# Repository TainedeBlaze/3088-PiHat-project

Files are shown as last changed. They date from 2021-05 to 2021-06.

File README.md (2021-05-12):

# 3088-PiHat-project
# Taine de Buys
# 2021/05/12

brief description of what our PiHat does: 
We have designed a temperature sensor piHat, that will be able to measure the temperature of anything from a liquid to the ambient room temperature, and convey this temperature through a set out LED outputs. Each LED can be configured to turn on for when the temperature surpasses a designated threshold. This is done through a comparator op amp configuration and potentiometers for each LED. The circuit has 3 subsysetms, a voltage regulator that sets the voltage going into the LEDs, the temperature sensor itself, and the output LEDs which also have a status LED that shows whether the piHat is recieving power. 

Edits have now been made in a seperate branch to prove i know whats cracking

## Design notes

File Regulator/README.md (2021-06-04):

Brief description of buck-boost regulator subsystem: This subsystem at it's input takes in 3.3V from the RaspberryPi and ouputs a stable 4.3V line to power the 
comparator-LED configurations and the TMP135 temperature sensor.

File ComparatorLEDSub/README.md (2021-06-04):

Brief description of Comparator-LED subsystem: This subsystem comprises of three comparator-LED configurations that are designed in such a way to ouput a voltage of
over 0.7 Volts to each LED based on the output data of the TMP135 temperature sesnor. The first comparator configuration outputs a high voltage resulting in the LED
displaying when Vdata (Voltage output of TMP135) is in the range of 0 - 20 degrees celcius respectively. The second configuration outputs a high to the second LED 
when the temperature is in the range 20 - 40 degrees clecius, and the third when the temperature is in the range 40 degrees celcius and above. In the case of 40 
degrees clecius and above, all three LED's are displaying.

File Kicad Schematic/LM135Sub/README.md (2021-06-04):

Brief description of LM135 temperature sensor subsystem: This subsystem is comprised of the TMP135 temperature sensor which has its input (powering terminal) 
connected to the output of of the buck boost regulator subsystem, and its output (Vdata) connected to the comparator-LED subsystem. The TMP335 temperature sensor at
0℃ outputs 2.73V, increasing by 10mV/℃.

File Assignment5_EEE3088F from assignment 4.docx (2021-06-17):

EEE088F 2021 Assignment 5

Temperature Sensor PiHat

ALTMIC003, DGDC001, DBYTAI001

10/06/2021

# Executive Summary [5]

The following report describes the design process, each submodule of the PiHat in detail, as well as the PCB design/development, and finally includes a reflection on the full design process. Various conclusions were drawn over the design process and are discussed in this report.

Each submodule - namely the power supply, the Comparator-LED’s and the LM135 temperature sensor submodules respectively - is discussed in depth. Lastly, the PCB design is discussed, and attached are screenshots of both the 3D and 2D models of the PCB design. Furthermore, hyperlinks to the git repository containing all relevant data and information for this PiHat design are listed in this report.

# Introduction [5]

Our PiHat is an analogue temperature sensor. The purpose of the Hat is to allow the user to get a visual indication as to the surrounding temperature. Temperature sensors can be used to measure ambient room temperature, or as a probe to measure the temperature of liquids or the inside temperature regulated appliances like freezers and fridges.

The circuit is powered from the 3.3V output pin from the Raspberry pi and is grounded into pin 6. The daughter board takes the 3.3V input and passes it through a buck-boost regulator IC, boosting the voltage to a steady 4.3V output to the rest of the subsystems. A physical switch is incorporated and allowing for the user to turn the Hat on and off while still being plugged in. If the circuit is closed, an LED will turn on to show that there is a voltage being outputted from the switch. This output will then run into an analogue temperature sensor that will be covered in a waterproof casing, so that it may be used as a probe. 3 LEDs display the output. 1 LED will turn on if the temperature is above 0 degrees Celsius. 2 lights will come on for a temperature of above 25 degrees Celsius, and all 3 lights will turn on for if the temperature is above 50 degrees Celsius. This was done using voltage dividers and op -amps in comparator circuit configurations. However, the voltage dividers could be exchanged for potentiometers, as this would allow for the threshold temperature of each LED to be set by the user.

## Project Subsystems Block Diagram [5]

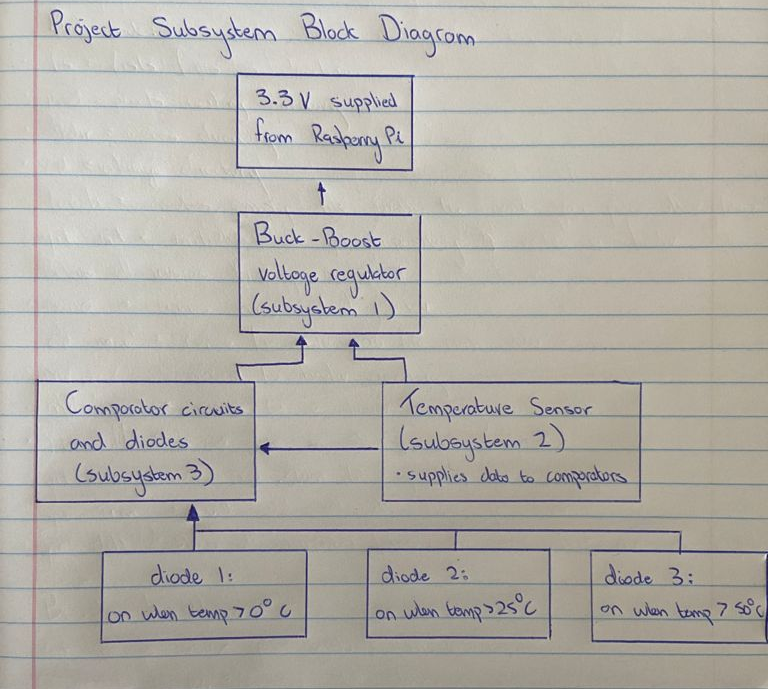
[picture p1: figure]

Figure 1: Subsystems Block Diagram.

# Design process [10]

The design process began by first specifying fixed meeting to delegate work and set sprint goals for each fortnite, with a design review happening with a tutor taking place in the weeks in between where we could discuss and reflect on progress. An initial idea was developed and use cases were specified. A circuit was developed comprising of 4 separate subsystems that met each of the requirements of our use cases

(available here: https://github.com/TainedeBlaze/3088-PiHat-project/blob/main/Project%20Submissions/EEE088F%202021%20Assignment%201%20.pdf (https://github.com/TainedeBlaze/3088-PiHat-project/blob/main/Project%20Submissions/EEE088F%202021%20Assignment%201%20.pdf))

After this submission, the team began to simulate each subsystem on LT Spice to see if the desired output would be achieved. Our first subsystem, the voltage regulator, became a source of concern as the initial design did not lie within the scope of the project design requirements. As such, this design evolved into a buck switching regulator, before finally a buck-boost voltage regulator IC component was chosen. Another point of inflection for the design came in our temperature sensor subsystem, as the LM355 sensors simulation had a different temperature to voltage relationship than the data sheets. This led to changing resistor values in order to hit the desired output.

(calculated and explained in depth here: https://github.com/TainedeBlaze/3088-PiHat-project/blob/main/Project%20Submissions/Assignment%202%20submission.pdf )

## Power Supply submodule [10]

This power supply submodule is solely made up of an LTC3442 integrated circuit which acts as a buck-boost regulator, providing a stable 4.4V output from the 3.3V input supplied by the RaspberryPi. In order for this submodule to work congruently with the rest of the circuit, it has to have various specifications that fit the criteria of the following two submodules (i.e the TMP135 temperature sensor submodule and the Comparator-LED submodule). These specifications include:

- Vin (pin 1) = 3.3V (DC supply from the RaspberryPi).
- Vout = 4.4V (This value is reached as a result of the external configuration of the LTC3442 integrated circuit).

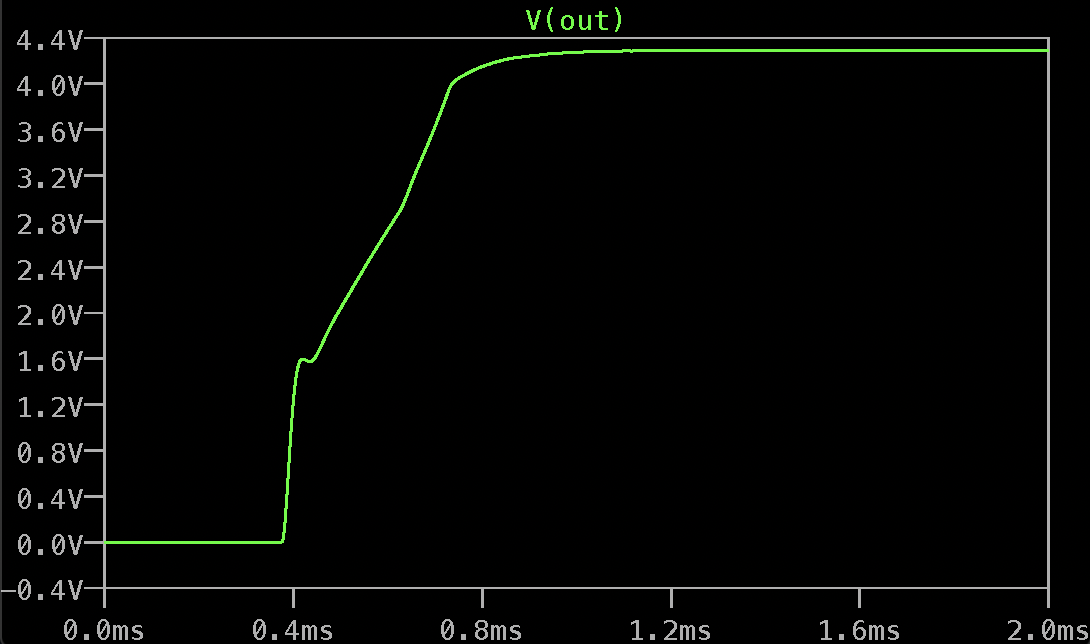
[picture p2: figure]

Figure 2: LT Spice simulation of Vout of the LTC3442 IC.

https://github.com/TainedeBlaze/3088-PiHat-project/blob/main/Regulator/BuckBoost.png

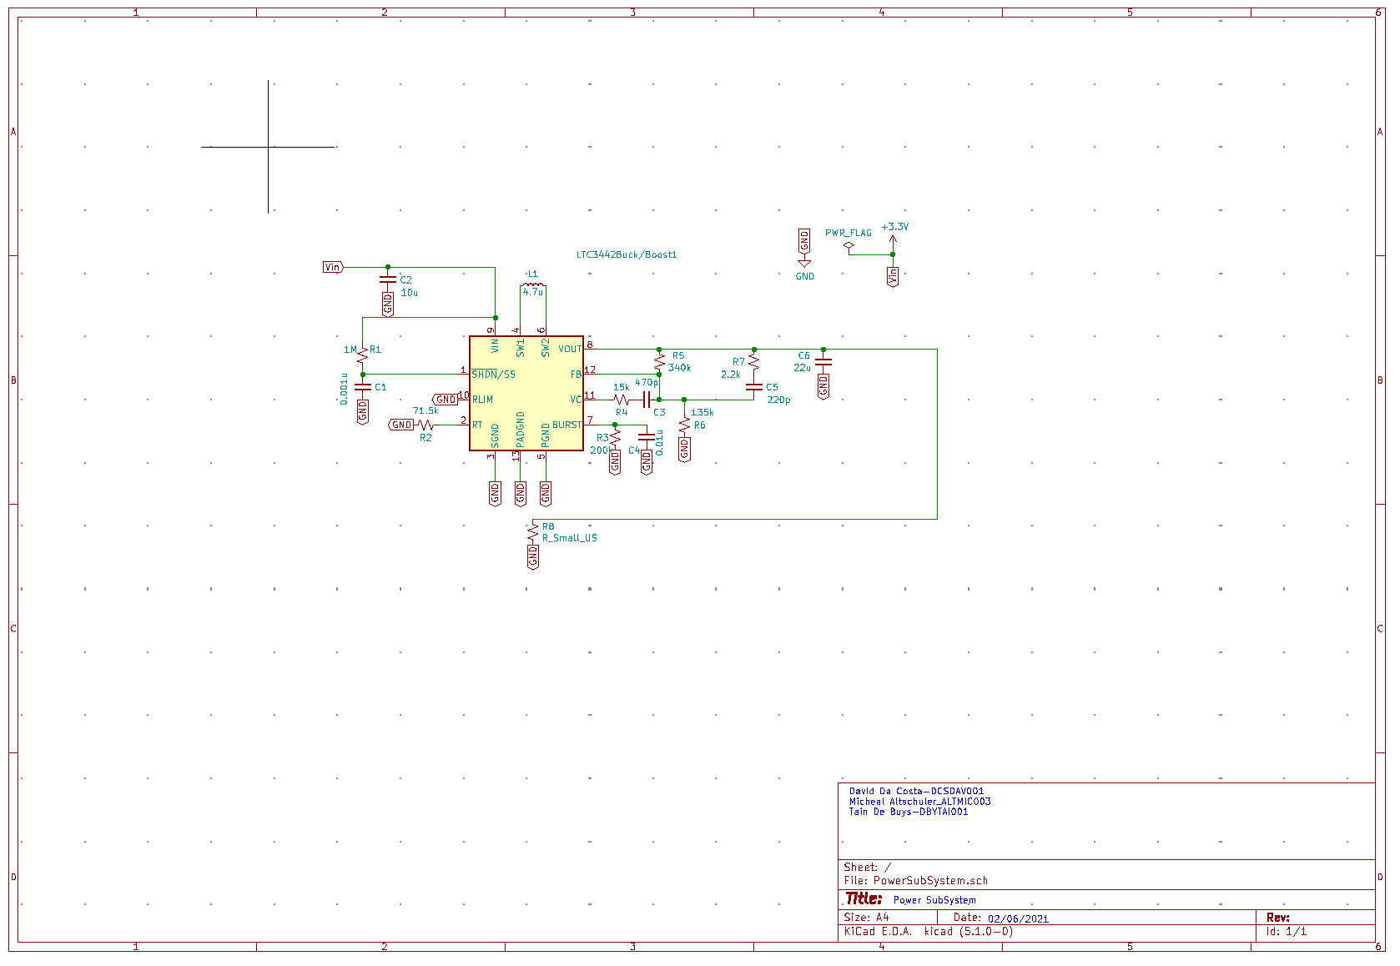
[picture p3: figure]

Figure 3: Screenshot of LTC3442 KiCad schematic

https://github.com/TainedeBlaze/3088-PiHat-project/blob/main/Regulator/BuckBoostKiCad.png

This submodule fits seamlessly into the design of the full circuit. It reliably outputs the desired 4.4V needed by the TMP135 and the comparator-LED configurations.

## Status Comparator-LEDs submodule [10]

This subsystem is made up of a series of comparator-LED configurations used to display the current temperature threshold met and to further display whether the circuit/PiHat is on (receiving power from the Buck Switch Regulator) or not. Three of the configurations have their non-inverting input connected to the TMP335 data line, and their inverting input connected to the 4.4V line supplied by the Buck Switch Regulator. Each of the three inverting inputs implement a voltage divider which determines when the comparator will output high based on the voltage supplied by the TMP335.

For the status LEDs, 3 simulations are run showing the 3 states that our output diodes are in. The thresholds were predefined as 0 ℃, 25 ℃ and 50 ℃ .

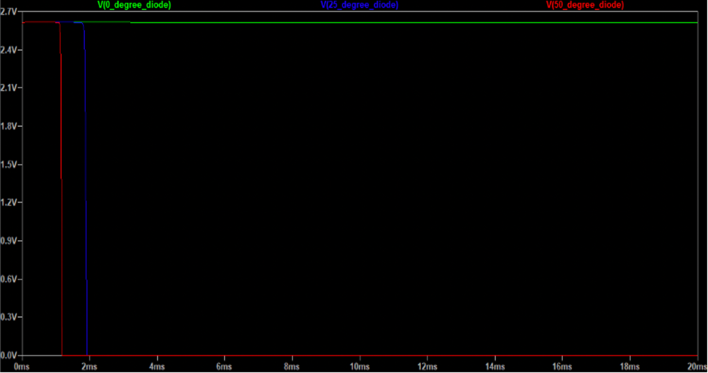
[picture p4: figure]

Figure 4: Simulation when temperature is 2°C .

https://github.com/TainedeBlaze/3088-PiHat-project/blob/main/ComparatorLEDSub/2degrees.png

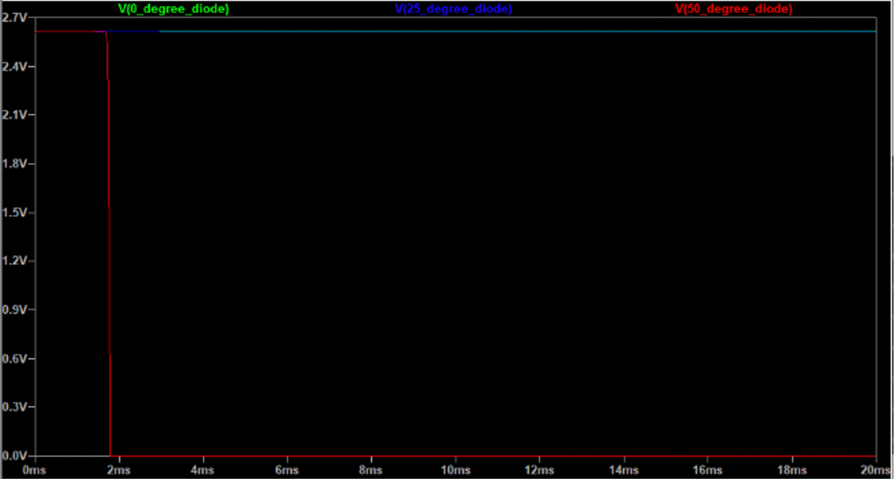
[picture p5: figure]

Figure 5: Simulation when temperature is 26°C .

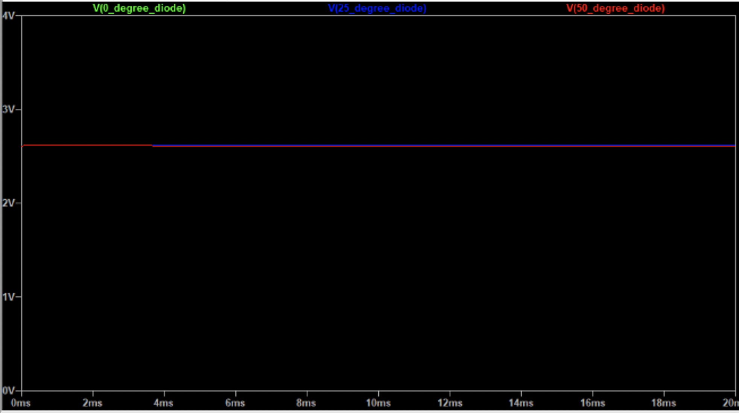
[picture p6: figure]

https://github.com/TainedeBlaze/3088-PiHat-project/blob/main/ComparatorLEDSub/26degrees.png

Figure 6: Simulation when temperature is 52°C .

https://github.com/TainedeBlaze/3088-PiHat-project/blob/main/ComparatorLEDSub/52degrees.png

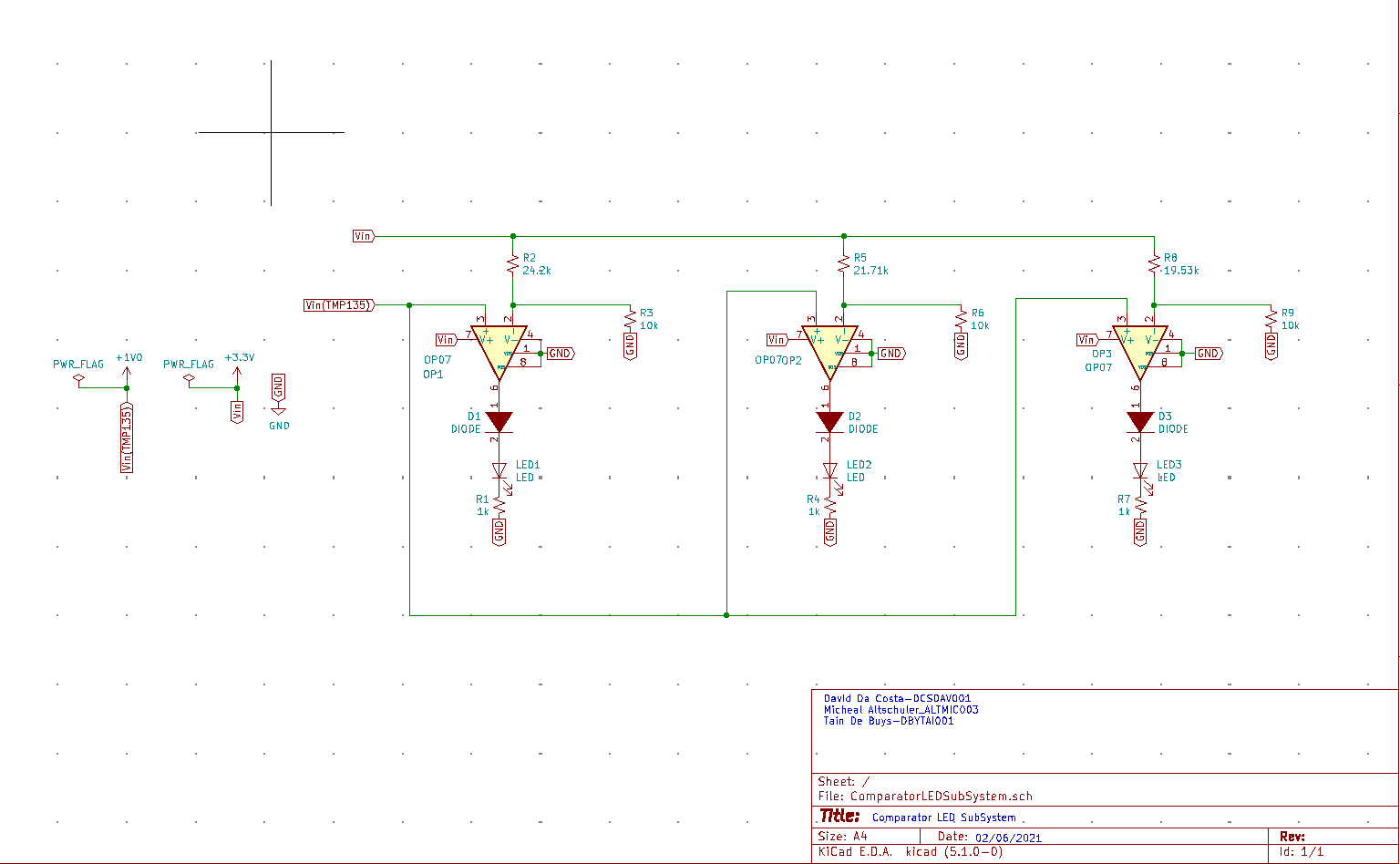
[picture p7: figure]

Figure 7: Screenshot of the Comparator-LED subsystem KiCad schematic.

https://github.com/TainedeBlaze/3088-PiHat-project/blob/main/ComparatorLEDSub/ComparatorLEDKiCad.png

According to all the theoretical conclusions drawn when designing this submodule, and from further subsequent LT Spice simulation, the status LED’s operate as they are supposed to. One LED will turn on within the first temperature range, two will turn on in the second, and finally all three will turn on in the third. It’s tough to draw a conclusion on the overall operation of this subsystem in a real-life situation as this circuit was only theoretically designed. However, if one did have to supply this subsystem with 4.4V (supplied by the LTC3442), it theoretically should work perfectly with no safety issues.

## LM135 Temperature Sensor submodule [10]

This subsystem is made up of the LM135 temperature sensor - the component being powered by the 4.4V line outputted by the Buck Switch Regulator, and further supplies the data needed by the comparator-LED configurations to output/display their temperature thresholds based on the voltage supplied by the LM335.

The LM355 temperature sensor was imported as an external library into LT Spice for the simulations. The data sheet supplied with the LM335 stated that the correlation between output voltage from the sensor and ambient temperature is given as: ∴V=5 ×10^(-3) T+1.2569 (eqn.1). Where T is measured in degrees Celsius.

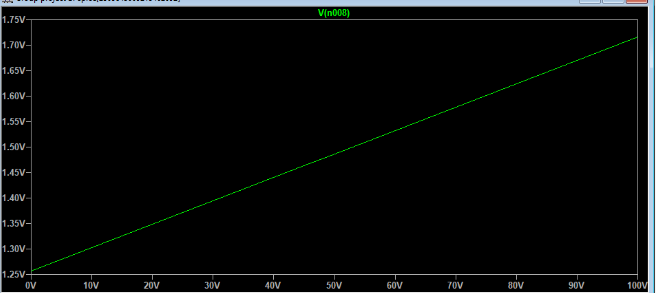
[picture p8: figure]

Figure 8: Output voltage of LM135 for different temperatures (specified on the x-axis).

https://github.com/TainedeBlaze/3088-PiHat-project/blob/main/LM135Sub/tmp135Simulation.png

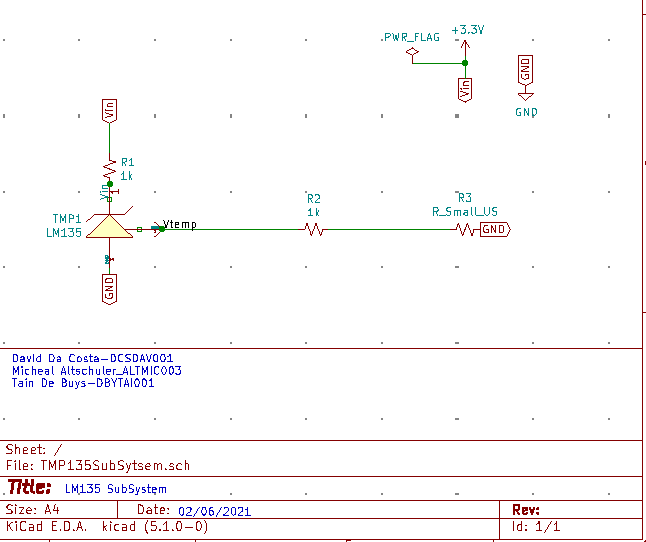
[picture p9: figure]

Figure: KiCad schematic for the LM135 submodule.

https://github.com/TainedeBlaze/3088-PiHat-project/blob/main/LM135Sub/LM135KiCad_Schematic%20.png

In conclusion to this subsystem, it can be said with certainty that it will operate in a real-life situation safely. However, after running a sweep across the temperature from 0 to 100 (depicted below where the x axis represents temperature), it was evident that the LT spice component had a slightly different relationship to the theoretical relationship specified. Thus, a new equation was calculated for the relationship between the output voltage of the sensor and the temperature discussed above (eqn.1). For the status LED’s to accurately display which temperature threshold is met, the LM335 needs to output the correct voltage to the comparators based on their respective temperature thresholds. From the LM335 data sheet, it was seen that at 0℃, the sensor would output 2.73V, increasing by 10mV/℃. However, after testing on LT Spice, a different outcome was observed. For experimental and circuit accuracy, the simulated results for Vdata were used in place of the theoretical values. This ensured that the status LEDs turned on at the correct temperatures. Thus, the specifications for this subsystem were accurately met through empirical evidence from the simulation rather than theory.

# Complete Schematic

The following image shows the final Pihat schematic containing all subsystems:

Figure Screenshot of complete Schematic

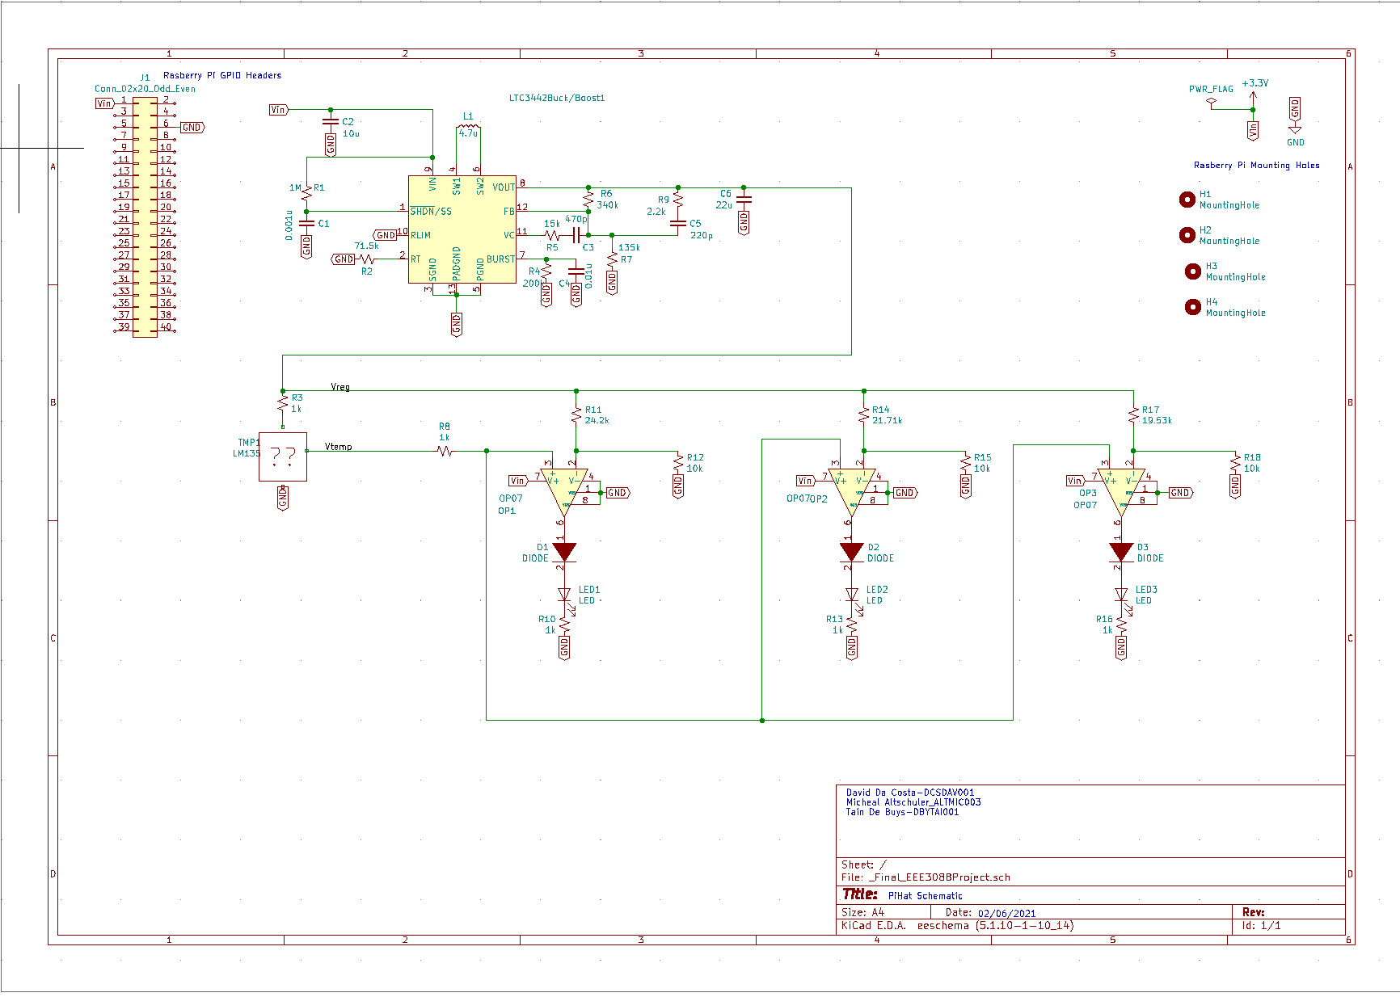
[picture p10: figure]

The schematic can be found using the following link:
https://github.com/TainedeBlaze/3088-PiHat-project/tree/main/Kicad%20Schematic

# PCB [10]

The dimensions of the PCB are: 65X30mm
The mounting hole’s diameters are 3.5mm
There are two connection points needed to be made to the Raspberry Pi Vin and GND these The Vin supplied should be connected to the 3.3V supply from the Raspberry Pi (pin 1) and the Ground (pin 6) Please note we have found an issue with our PCB as we have not properly formatted the size, input and ground pins. This will be adjusted before next submission.

The bill of materials can be found here :

https://github.com/TainedeBlaze/3088-PiHat-project/tree/main/PCB's%20Bill%20Of%20Materials

A how to guide on manufacturing one’s own temperature sensor PCB can be found using the following link:

https://github.com/TainedeBlaze/3088-PiHat-project/tree/main/Howto

How to use your PiHat link can be found below (same link as above):

https://github.com/TainedeBlaze/3088-PiHat-project/tree/main/Howto

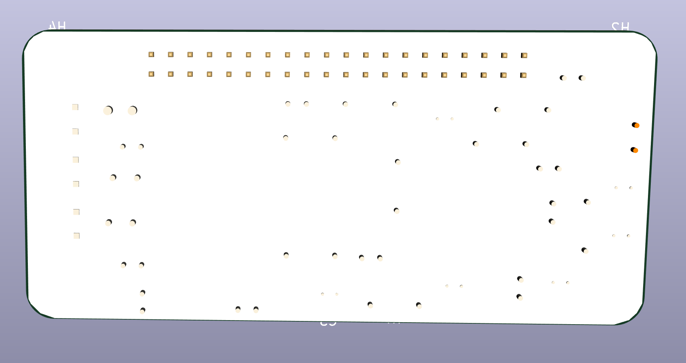
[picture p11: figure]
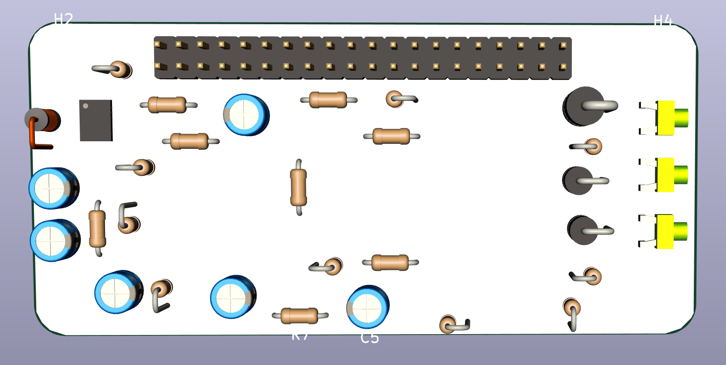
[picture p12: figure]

Figure: Screenshots displaying the front(right) and back(left) of the 3D PCB

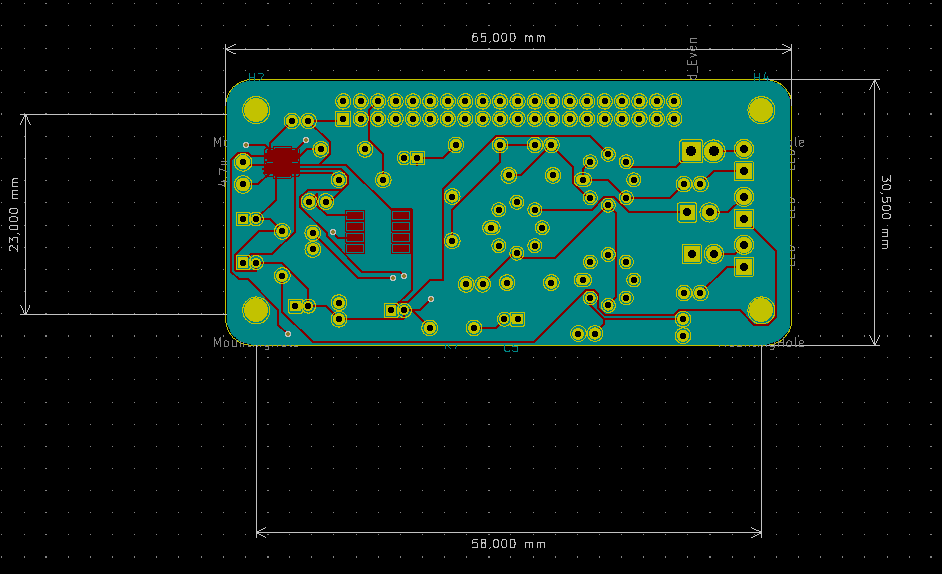
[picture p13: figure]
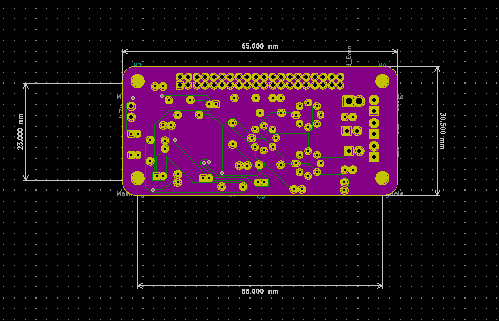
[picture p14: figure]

Figure: Screenshots of 2D PCB.

Gerber Files can be found using the link below:

https://github.com/TainedeBlaze/3088-PiHat-project/tree/main/Gerber%20Files%20Final

PCB and nested files can be found using the link below:
https://github.com/TainedeBlaze/3088-PiHat-project/tree/main/PCB

# Conclusion [10]

During the initial stages of the design process, each subsystem of the PiHat was designed using theoretically calculated values that would at a later stage be used when designing the simulated version of the full circuit (all subsystems combined). Issues were encountered when calculating comparator resistor values as the temperature coefficient provided by the LM135 datasheet did not match the simulated results. A new temperature coefficient was then determined for temperature and voltage based on the LT Spice components. The threshold temperatures selected are 0℃, 25℃ and 50℃ and the resistor voltage divider values of each comparator configuration had to be edited until the desired output was achieved.

As mentioned above It’s tough to draw a conclusion on the overall operation of this system as a whole in a real-life situation as this circuit was only theoretically designed. However, if one did have to supply this ssystem with 3.3V from the Raspberry Pi to the LTC3442 which subsequently provides 4.4V line to the rest of the circuit, it theoretically should work perfectly with no safety issues.

During the PCB design stage we had to create our own component for LM135 temperature sensor and build the schematic for the sensor. This sensor was then placed into our larger schematic for the PiHat. The next step was to generate the netlist and build the PCB. This followed by the timely process of connecting nodes and ensuring all rule checks held zero errors.

Furthermore, the implementation of an agile approach to this project enabled the group to work as efficiently as possible. Particularly the use of SCRUM by short sprint periods in the form of fortnightly meetings and submissions, with the specifications changing according to new developments in the project.

The design process of this PiHat gave the group a great deal of insight into the components that make up this circuit, as well as how LT Spice and KiCad operate. Specifically the creation of a library component for the LM135 on LT Spice gave the group intuition on the workings of the software needed to design this system. However, there were various aspects of this assignment that resulted in unanswered questions that had to be solved using manipulation of results and component values rather than known calculations - although this was a direct result of the imported temperature sensor not fitting its datasheet, this assignment has been useful in conveying the complexities in design processes.

# Reflection on design process [5]

In retrospect, this project has taught us a lot about the design process and challenges one should expect to face in developing an idea. The course provided a streamlined process, which allowed for compartmentalization of the project. Breaking the circuit down into subsystems and developing block diagrams was an excellent way to allow for simultaneous development. The use of regular design reviews with the tutor was also great as it allowed the team time to set short term goals, and then reflect over the outcome of each goal at a later stage. This kept us focussed and maintained clarity.

SPICE was a great application to design and test our ideas, its hotkeys made it fast and easy to edit and change designs. However, the simulation did prove challenging when it came to simulating nonstandard components such as our temperature sensor, as the simulated component had slightly different characteristics as compared to the ones specified by its data sheet. As a result, we needed to change other components to match the output of our simulated values rather than our theoretical ones. This was important in teaching us about the need to adapt to the tools available to us rather than trying to stick with theory that does not work in practice.

The team all agreed that GitHub was an extremely useful tool in working collaboratively on the assignment. It allowed for fast transfer of information and served as a useful tool for version control and documenting our progress.

Looking forward, the team would recommend a faster feedback process, as there were moments where time to fix errors was limited in between submissions. However, we understand that this is a difficult request given the nature of online learning and the Pandemic. We are grateful for the experience and have a far better understanding of the process for designs.

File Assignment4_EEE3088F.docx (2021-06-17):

EEE088F 2021 Assignment 4

Temperature Sensor PiHat

ALTMIC003, DGDC001, DBYTAI001

10/06/2021

# Executive Summary [5]

The following report describes the design process, each submodule of the PiHat in detail, as well as the PCB design/development, and finally includes a reflection on the full design process. Various conclusions were drawn over the design process and are discussed in this report.

Each submodule - namely the power supply, the Comparator-LED’s and the LM135 temperature sensor submodules respectively - is discussed in depth. Lastly, the PCB design is discussed, and attached are screenshots of both the 3D and 2D models of the PCB design. Furthermore, hyperlinks to the git repository containing all relevant data and information for this PiHat design are listed in this report.

# Introduction [5]

Our PiHat is an analogue temperature sensor. The purpose of the Hat is to allow the user to get a visual indication as to the surrounding temperature. Temperature sensors can be used to measure ambient room temperature, or as a probe to measure the temperature of liquids or the inside temperature regulated appliances like freezers and fridges.

The circuit is powered from the 3.3V output pin from the Raspberry pi and is grounded into pin 6. The daughter board takes the 3.3V input and passes it through a buck-boost regulator IC, boosting the voltage to a steady 4.3V output to the rest of the subsystems. A physical switch is incorporated and allowing for the user to turn the Hat on and off while still being plugged in. If the circuit is closed, an LED will turn on to show that there is a voltage being outputted from the switch. This output will then run into an analogue temperature sensor that will be covered in a waterproof casing, so that it may be used as a probe. 3 LEDs display the output. 1 LED will turn on if the temperature is above 0 degrees Celsius. 2 lights will come on for a temperature of above 25 degrees Celsius, and all 3 lights will turn on for if the temperature is above 50 degrees Celsius. This was done using voltage dividers and op -amps in comparator circuit configurations. However, the voltage dividers could be exchanged for potentiometers, as this would allow for the threshold temperature of each LED to be set by the user.

## Project Subsystems Block Diagram [5]


Figure 1: Subsystems Block Diagram.

# Design process [10]

The design process began by first specifying fixed meeting to delegate work and set sprint goals for each fortnite, with a design review happening with a tutor taking place in the weeks in between where we could discuss and reflect on progress. An initial idea was developed and use cases were specified. A circuit was developed comprising of 4 separate subsystems that met each of the requirements of our use cases

(available here: https://github.com/TainedeBlaze/3088-PiHat-project/blob/main/Project%20Submissions/EEE088F%202021%20Assignment%201%20.pdf (https://github.com/TainedeBlaze/3088-PiHat-project/blob/main/Project%20Submissions/EEE088F%202021%20Assignment%201%20.pdf))

After this submission, the team began to simulate each subsystem on LT Spice to see if the desired output would be achieved. Our first subsystem, the voltage regulator, became a source of concern as the initial design did not lie within the scope of the project design requirements. As such, this design evolved into a buck switching regulator, before finally a buck-boost voltage regulator IC component was chosen. Another point of inflection for the design came in our temperature sensor subsystem, as the LM355 sensors simulation had a different temperature to voltage relationship than the data sheets. This led to changing resistor values in order to hit the desired output.

(calculated and explained in depth here: https://github.com/TainedeBlaze/3088-PiHat-project/blob/main/Project%20Submissions/Assignment%202%20submission.pdf )

## Power Supply submodule [10]

This power supply submodule is solely made up of an LTC3442 integrated circuit which acts as a buck-boost regulator, providing a stable 4.4V output from the 3.3V input supplied by the RaspberryPi. In order for this submodule to work congruently with the rest of the circuit, it has to have various specifications that fit the criteria of the following two submodules (i.e the TMP135 temperature sensor submodule and the Comparator-LED submodule). These specifications include:

- Vin (pin 1) = 3.3V (DC supply from the RaspberryPi).
- Vout = 4.4V (This value is reached as a result of the external configuration of the LTC3442 integrated circuit).


Figure 2: LT Spice simulation of Vout of the LTC3442 IC.

https://github.com/TainedeBlaze/3088-PiHat-project/blob/main/Regulator/BuckBoost.png


Figure 3: Screenshot of LTC3442 KiCad schematic

https://github.com/TainedeBlaze/3088-PiHat-project/blob/main/Regulator/BuckBoostKiCad.png

This submodule fits seamlessly into the design of the full circuit. It reliably outputs the desired 4.4V needed by the TMP135 and the comparator-LED configurations.

## Status Comparator-LEDs submodule [10]

This subsystem is made up of a series of comparator-LED configurations used to display the current temperature threshold met and to further display whether the circuit/PiHat is on (receiving power from the Buck Switch Regulator) or not. Three of the configurations have their non-inverting input connected to the TMP335 data line, and their inverting input connected to the 4.4V line supplied by the Buck Switch Regulator. Each of the three inverting inputs implement a voltage divider which determines when the comparator will output high based on the voltage supplied by the TMP335.

For the status LEDs, 3 simulations are run showing the 3 states that our output diodes are in. The thresholds were predefined as 0 ℃, 25 ℃ and 50 ℃ .


Figure 4: Simulation when temperature is 2°C .

https://github.com/TainedeBlaze/3088-PiHat-project/blob/main/ComparatorLEDSub/2degrees.png


Figure 5: Simulation when temperature is 26°C .


https://github.com/TainedeBlaze/3088-PiHat-project/blob/main/ComparatorLEDSub/26degrees.png

Figure 6: Simulation when temperature is 52°C .

https://github.com/TainedeBlaze/3088-PiHat-project/blob/main/ComparatorLEDSub/52degrees.png


Figure 7: Screenshot of the Comparator-LED subsystem KiCad schematic.

https://github.com/TainedeBlaze/3088-PiHat-project/blob/main/ComparatorLEDSub/ComparatorLEDKiCad.png

According to all the theoretical conclusions drawn when designing this submodule, and from further subsequent LT Spice simulation, the status LED’s operate as they are supposed to. One LED will turn on within the first temperature range, two will turn on in the second, and finally all three will turn on in the third. It’s tough to draw a conclusion on the overall operation of this subsystem in a real-life situation as this circuit was only theoretically designed. However, if one did have to supply this subsystem with 4.4V (supplied by the LTC3442), it theoretically should work perfectly with no safety issues.

## LM135 Temperature Sensor submodule [10]

This subsystem is made up of the LM135 temperature sensor - the component being powered by the 4.4V line outputted by the Buck Switch Regulator, and further supplies the data needed by the comparator-LED configurations to output/display their temperature thresholds based on the voltage supplied by the LM335.

The LM355 temperature sensor was imported as an external library into LT Spice for the simulations. The data sheet supplied with the LM335 stated that the correlation between output voltage from the sensor and ambient temperature is given as: ∴V=5 ×10^(-3) T+1.2569 (eqn.1). Where T is measured in degrees Celsius.


Figure 8: Output voltage of LM135 for different temperatures (specified on the x-axis).

https://github.com/TainedeBlaze/3088-PiHat-project/blob/main/LM135Sub/tmp135Simulation.png


Figure: KiCad schematic for the LM135 submodule.

https://github.com/TainedeBlaze/3088-PiHat-project/blob/main/LM135Sub/LM135KiCad_Schematic%20.png

In conclusion to this subsystem, it can be said with certainty that it will operate in a real-life situation safely. However, after running a sweep across the temperature from 0 to 100 (depicted below where the x axis represents temperature), it was evident that the LT spice component had a slightly different relationship to the theoretical relationship specified. Thus, a new equation was calculated for the relationship between the output voltage of the sensor and the temperature discussed above (eqn.1). For the status LED’s to accurately display which temperature threshold is met, the LM335 needs to output the correct voltage to the comparators based on their respective temperature thresholds. From the LM335 data sheet, it was seen that at 0℃, the sensor would output 2.73V, increasing by 10mV/℃. However, after testing on LT Spice, a different outcome was observed. For experimental and circuit accuracy, the simulated results for Vdata were used in place of the theoretical values. This ensured that the status LEDs turned on at the correct temperatures. Thus, the specifications for this subsystem were accurately met through empirical evidence from the simulation rather than theory.

# PCB [10]

The dimensions of the PCB are: 65X30mm
The mounting hole’s diameters are 3.5mm
There are two connection points needed to be made to the Raspberry Pi Vin and GND these The Vin supplied should be connected to the 3.3V supply from the Raspberry Pi (pin 1) and the Ground (pin 6) Please note we have found an issue with our PCB as we have not properly formatted the size, input and ground pins. This will be adjusted before next submission.

The bill of materials can be found here :

https://github.com/TainedeBlaze/3088-PiHat- project/tree/main/PCB's%20Bill%20Of%20Materials
A how to guide on manufacturing one’s own temperature sensor PCB can be found using the following link: https://github.com/TainedeBlaze/3088-PiHat-project/tree/main/Howto
How to use your PiHat link can be found below (same link as above):

https://github.com/TainedeBlaze/3088-PiHat-project/tree/main/Howto

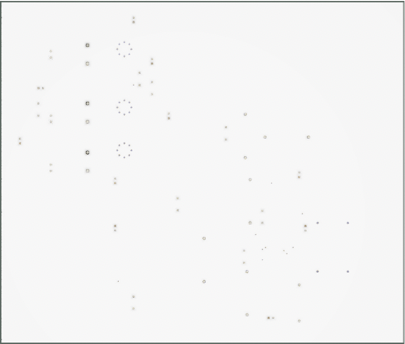
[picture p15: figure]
page1image29977360
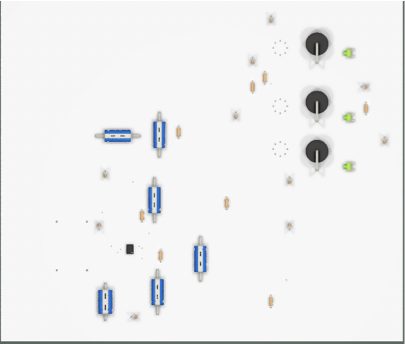
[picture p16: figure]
page1image29976736

Figure: Screenshots displaying the front(right) and back(left) of the 3D PCB

https://github.com/TainedeBlaze/3088-PiHat-project/blob/main/PCB%20and%20Gerber%20Files/3D_PCB.png

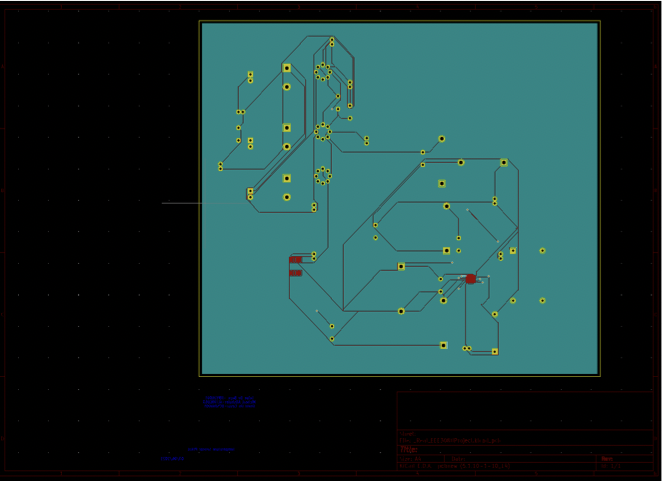
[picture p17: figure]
page1image29976320
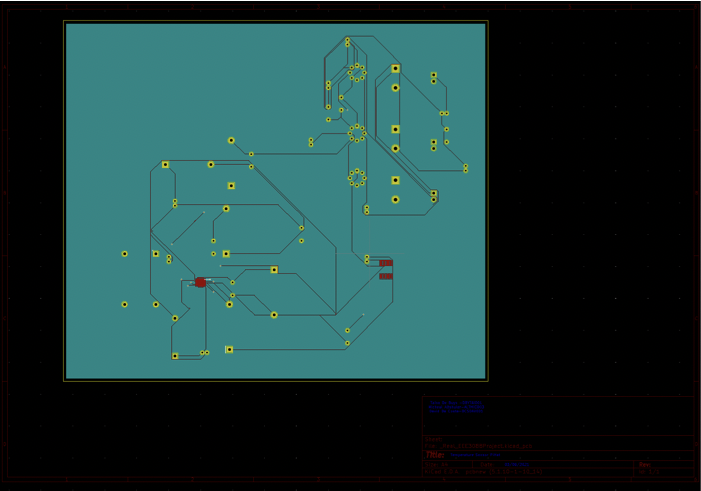
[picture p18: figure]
page1image29976112

Figure: Screenshots of 2D PCB.

https://github.com/TainedeBlaze/3088-PiHat-project/blob/main/PCB%20and%20Gerber%20Files/2D_PCB.png

# Conclusion [10]

During the initial stages of the design process, each subsystem of the PiHat was designed using theoretically calculated values that would at a later stage be used when designing the simulated version of the full circuit (all subsystems combined). Issues were encountered when calculating comparator resistor values as the temperature coefficient provided by the LM135 datasheet did not match the simulated results. A new temperature coefficient was then determined for temperature and voltage based on the LT Spice components. The threshold temperatures selected are 0℃, 25℃ and 50℃ and the resistor voltage divider values of each comparator configuration had to be edited until the desired output was achieved.

As mentioned above It’s tough to draw a conclusion on the overall operation of this system as a whole in a real-life situation as this circuit was only theoretically designed. However, if one did have to supply this ssystem with 3.3V from the Raspberry Pi to the LTC3442 which subsequently provides 4.4V line to the rest of the circuit, it theoretically should work perfectly with no safety issues.

During the PCB design stage we had to create our own component for LM135 temperature sensor and build the schematic for the sensor. This sensor was then placed into our larger schematic for the PiHat. The next step was to generate the netlist and build the PCB. This followed by the timely process of connecting nodes and ensuring all rule checks held zero errors.

Furthermore, the implementation of an agile approach to this project enabled the group to work as efficiently as possible. Particularly the use of SCRUM by short sprint periods in the form of fortnightly meetings and submissions, with the specifications changing according to new developments in the project.

The design process of this PiHat gave the group a great deal of insight into the components that make up this circuit, as well as how LT Spice and KiCad operate. Specifically the creation of a library component for the LM135 on LT Spice gave the group intuition on the workings of the software needed to design this system. However, there were various aspects of this assignment that resulted in unanswered questions that had to be solved using manipulation of results and component values rather than known calculations - although this was a direct result of the imported temperature sensor not fitting its datasheet, this assignment has been useful in conveying the complexities in design processes.

# Reflection on design process [5]

In retrospect, this project has taught us a lot about the design process and challenges one should expect to face in developing an idea. The course provided a streamlined process, which allowed for compartmentalization of the project. Breaking the circuit down into subsystems and developing block diagrams was an excellent way to allow for simultaneous development. The use of regular design reviews with the tutor was also great as it allowed the team time to set short term goals, and then reflect over the outcome of each goal at a later stage. This kept us focussed and maintained clarity.

SPICE was a great application to design and test our ideas, its hotkeys made it fast and easy to edit and change designs. However, the simulation did prove challenging when it came to simulating nonstandard components such as our temperature sensor, as the simulated component had slightly different characteristics as compared to the ones specified by its data sheet. As a result, we needed to change other components to match the output of our simulated values rather than our theoretical ones. This was important in teaching us about the need to adapt to the tools available to us rather than trying to stick with theory that does not work in practice.

The team all agreed that GitHub was an extremely useful tool in working collaboratively on the assignment. It allowed for fast transfer of information and served as a useful tool for version control and documenting our progress.

Looking forward, the team would recommend a faster feedback process, as there were moments where time to fix errors was limited in between submissions. However, we understand that this is a difficult request given the nature of online learning and the Pandemic. We are grateful for the experience and have a far better understanding of the process for designs.

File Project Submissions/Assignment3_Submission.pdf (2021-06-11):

# EEE088F 2021 Assignment3 Template

# Schematics [30]

## Voltage regulator Schematic [10]

https://github.com/TainedeBlaze/3088-PiHat-project/tree/main/Regulator

## Temperature Sensor Schematic [10]

https://github.com/TainedeBlaze/3088-PiHat-project/tree/main/LM135Sub

## Comparator Schematic [10]

https://github.com/TainedeBlaze/3088-PiHat-project/tree/main/ComparatorLEDSub

# PCB [20]

## Micro PiHAT [17]

- Provide hyperlink to folder in gitlab repo containing the source files to the placed and routed PCB
https://github.com/TainedeBlaze/3088-PiHat-project/tree/main/PCB%20and%20Gerber%20Files (https://github.com/TainedeBlaze/3088-PiHat-project/tree/main/PCB%20and%20Gerber%20Files)

## Design Rule Checks [3]

- Screen shot the DRC configuration window to show what rules you applied
- Indicate if your final design is passing all checks and if not explain why. From the screenshot below it is evident that our design did meet all the necessary requirements in the design check.

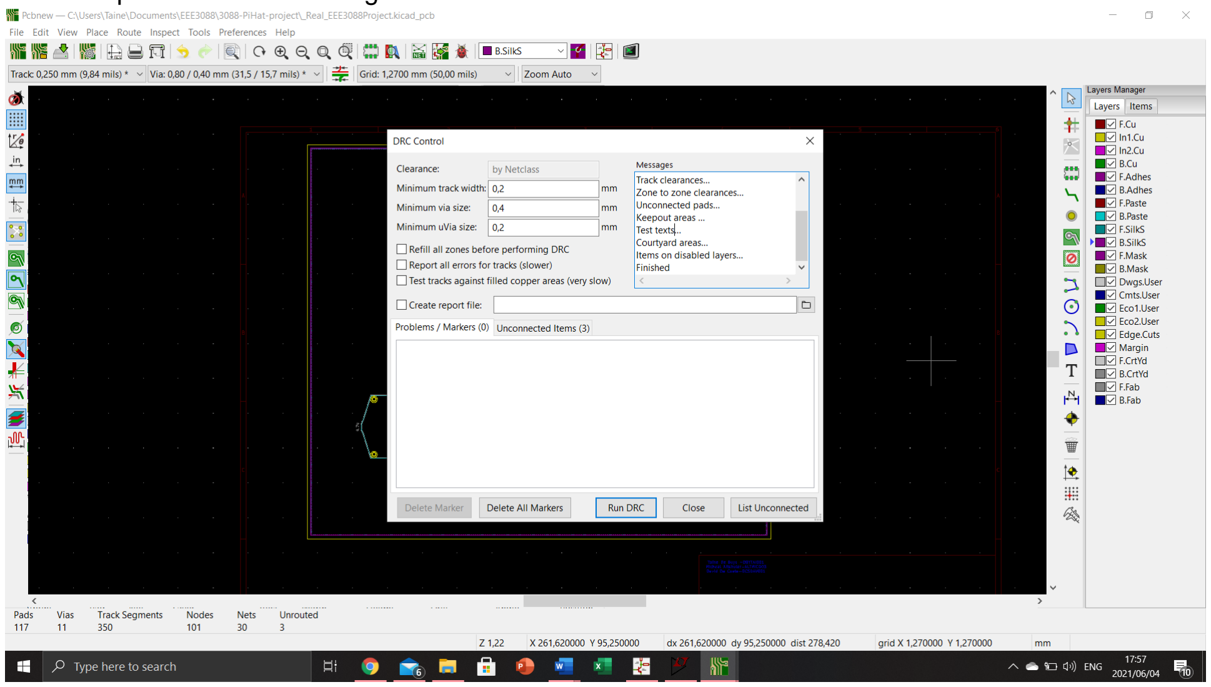
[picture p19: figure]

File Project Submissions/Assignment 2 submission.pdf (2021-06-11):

## EEE3088F Group Project Assignment 2

### 1. Power Supply Subsystem

1.1)The circuit simulations for the Design show how the Buck regulator successfully steps down the supply voltage of the circuit. There is an initial delay where the output voltage slowly increases, before the circuit reaches a stable state at 4.4 V. Upon closer inspection, you can see that the output line is sinusoidal, due to the MOSFET and inductor pair, which leads to this as the inductor charges and discharges based on the state of the MOSFET, with a rate of change that is dependant on the duty cycle of the regulator.

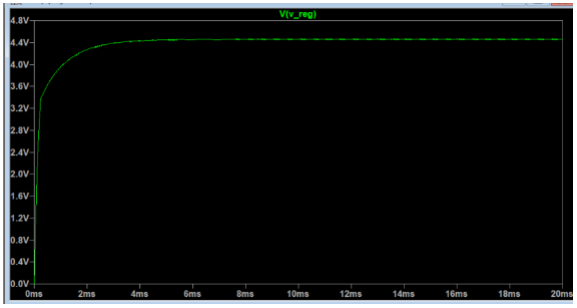
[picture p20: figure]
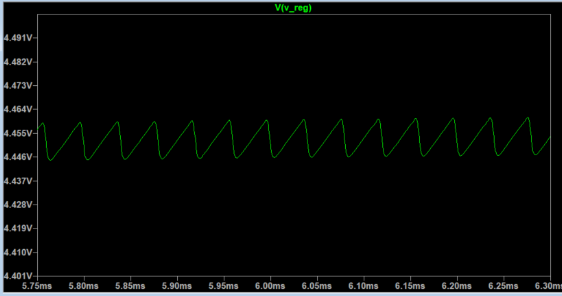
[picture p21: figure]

1.2)

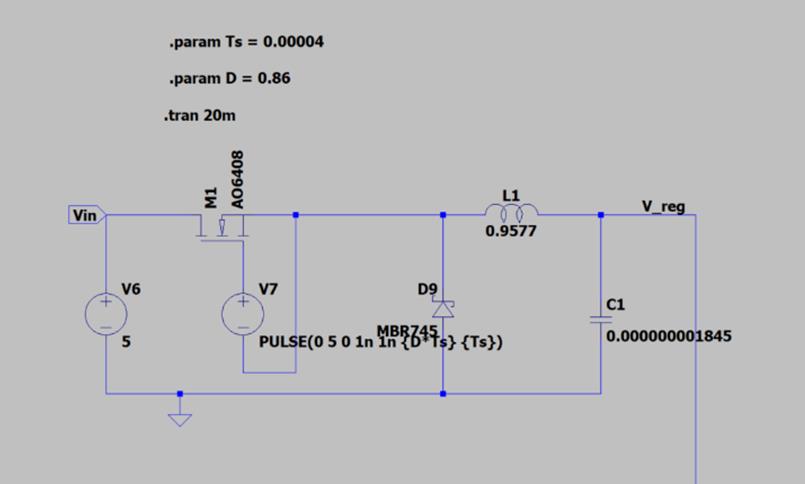
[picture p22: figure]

1.3) Our PiHat is powered from the 5V GPIO output pin from our Raspberry Pi (pin 2) and is grounded into pin 6. In Order to protect the PiHat and to ensure a constant voltage is supplied to the circuit, a buck switching mode regulator was used to step down the voltage from 5V to 4.4 V to ensure that the input voltage falls comfortably within the maximum voltage specifications of the LM335 temperature sensor. For this to work, there would need to be a pulse wave supplied to the MOSFET, with a frequency chosen to be 25 kHz

The component values were calculated using the below equations provided for a Buck regulator and the help of a tutor:
Vin = 5V
Vout = 4.4V
Pout = 0.1 W

Iout =

Pout
Vout =

0.01
4.3

= 2.33mA
There is a fluctuation in I of roughly 20% in these configurations, ∆I = 4.66 × 10⁻⁴ A

duty cycle is given as

Vout
Vin = 0.88

L =

Vout(1 − Duty cycle)
F∆I

=

4.4(1 − 0.88)
25 000(4.66 × 10⁻⁴)

= 0.0517 H

C was chosen to be a value of 1.165 × 10⁻⁷

1.4)This subsystem does meet the specifications needed for the rest of the circuit subsystems to operate optimally. As seen above, a Buck Switch Regulator was designed as part of the power supply subsystem with the purpose of regulating the 5V voltage supply rail of the Raspberry -providing the power to enable the operation of the temperature sensor PiHat as a whole. After assessment, it was deduced that the optimum operating voltage required by the TMP335 temperature sensor is 4.4V, while the RaspberryPi is only capable of supplying either a 3.3V or 5V DC voltage line to any circuit connected to it. Hence, the Buck Switch Voltage Regulator was implemented into the circuit to “buck” the 5V line from the RaspberryPi to a stable 4.4V line to the TMP335 and amplifier subsystem. Furthermore, the Buck Regulator makes use of a MOSFET and can therefore also act as a conventional switch, allowing one to halt current being supplied to the amplifier subsystem without switching off the RaspberryPi. Thus, it can be said that the power supply subsystem perfectly meets its specifications.

### 2. Temperature Sensor running into Operational Amplifiers

2.1) The LM355 temperature sensor was imported as an external library into LT Spice for the simulations. The data sheet supplied with the LM335 stated that the correlation between output voltage from the sensor and ambient temperature is given as: V = (10 × 10⁻³
)T + 2.73. Where T is
measured in degrees Celsius. However, after running a sweep across the temperature from 0 to 100 (depicted below where the x axis represents temperature), it was evident that the LT spice component had a slightly different relationship to the theoretical relationship specified. Calculations were done and a new relationship was defined as follows:

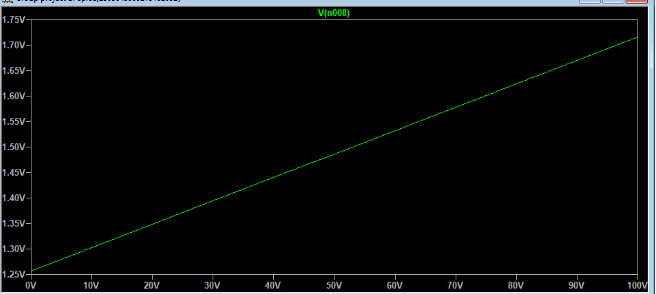
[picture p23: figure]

y = mx + c

Where c is the y intercept, found to be 1.257, the gradient of the graph was found by taking 2 points and calculating rise
run

, the points used were (20, 1.35) and (30, 1.395). m =

1.395−1.35
30−20

= 5 × 10⁻³

∴ V = 5 × 10⁻³T + 1.2569

To verify this, below are the output simulations from the temperature sensor for fixed temperatures:

T = 0° C:

V should equal
V = 5 × 10⁻³
(0) + 1.2569

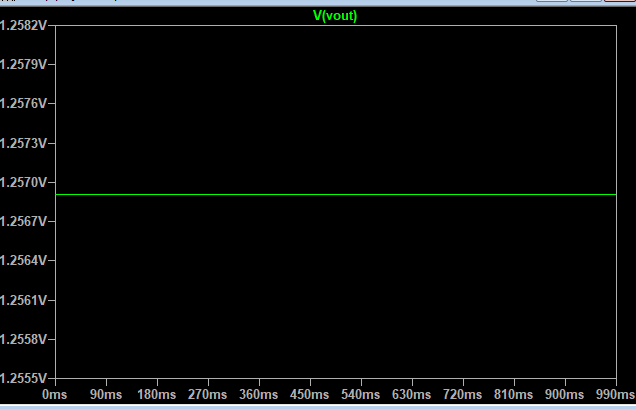
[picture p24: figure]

T = 15 ° C:

V should equal

V = 5 × 10⁻³
(15) + 1.2569

V = 1.3319


2.2) In the diagram below, the voltage source V2 represents ambient room temperature, as this is what allows one to simulate different temperatures.


2.3) This subsystem works by taking the 4.4 Volts outputted by the voltage regulator and passing it into the component. The sensor is essentially a Zener diode that has a reverse breakdown voltage that is proportional to absolute temperature. 4.4 in the input voltage, and the output voltage is determined by the ambient temperature. As the above equation conveys, the hotter the ambient temperature, the higher the voltage output from the sensor. A resistor is placed before the sensor to limit the current flowing into the LM335 and protect the component. Originally, the initial prototype involved using the LM35 temperature sensor, however there was no LT Spice component available to simulate this. As a result, we were forced to use the LM335 as this was the only temperature sensor that met the project requirements and could be simulated.
2.4) This subsystem is made up of the TMP335 temperature sensor - the component being powered by the 4.4V line outputted by the Buck Switch Regulator, and further supplies the data needed by the comparator-LED configurations to output/display their temperature thresholds based on the voltage supplied by the TMP335. For the status LED’s to accurately display which temperature threshold is met, the TMP335 needs to output the correct voltage to the comparators based on their respective temperature thresholds. From the TMP335 data sheet, it was seen that at 0℃, the sensor would output 2.73V, increasing by 10mV/℃. However, after testing on LT Spice, a different outcome was observed. For experimental and circuit accuracy, the simulated results for Vdata were used in place of the theoretical values. This ensured that the status LEDs turned on at the correct temperatures. Thus, the specifications for this subsystem were accurately met through empirical evidence from the simulation rather than theory.


### 3. Status LEDS

3.1) For the status LEDs, 3 simulations are run showing the 3 states that our output diodes are in. In real life there would be potentiometers that would allow the user to set each temperature threshold, but for the sake of the simulations, the thresholds were predefined as 0 ℃, 25 ℃ and 50 ℃ . The 4th status LED is used to show that the PiHat is receiving power.

Simulation 1: temperature at 2 ℃:

Simulation 2: Temperature at 26 ℃:


Simulation 3: 52 ℃:

The tests above show that each voltage goes high when the temperature is above the desired threshold.

3.2)

3.3) This subsystem is made up of a series of comparator-LED configurations used to display the current temperature threshold met and to further display whether the circuit/PiHat is on (receiving power from the Buck Switch Regulator) or not. Three of the configurations have their non-inverting input connected to the TMP335 data line, and their inverting input connected to the 4.4V line supplied by the Buck Switch Regulator. Each of the three inverting inputs implement a voltage divider which determines when the comparator will output high based on the voltage supplied by the TMP335.

To calculate the resistor values for each comparator circuit, we first needed to find the associated voltages for each temperature threshold. This was calculated as follows:

V(T) = 5 × 10⁻³T + 1.2569

V(0) = 5 × 10⁻³T + 1.2569

= 1.256 V for 0 ℃

V(25) = 5 × 10⁻³T + 1.2569

= 1.3819 V for 25 ℃

V(50) = 5 × 10⁻³T + 1.2569

= 1.5069 V for 50 ℃

Using the above voltages, the resistor values for each comparator circuit can be calculated. As temperature increases, the voltage across each non-inverting input of the opamps will increase. Once above each threshold value set by the inverting inputs, the Op Amp will allow current to flow into the LED, turning it on.

Resistors for 0 ℃ LED:

Vtℎresℎ = Vline(

R2
R1 + R2

)

let R2 = 10kΩ

1.256 = 4.4(

10
R1 + 10)

R1 = 25.03kΩ

Resistors for 25 ℃ LED:

Vtℎresℎ = Vline(

R2
R1 + R2

)

let R2 = 10kΩ

1.3819 = 4.4(

10
R1 + 10)

R1 = 21.84 kΩ

Resistors for 50 ℃ LED:

Vtℎresℎ = Vline(

R2
R1 + R2

)

let R2 = 10kΩ

1.5069 = 4.4(

10
R1 + 10)

R1 = 19.19kΩ

3.4) The circuit provides the right output for each threshold determined; however, it is difficult to say whether the subsystem meets the desired system specifications. On its own, the subsystem works as expected and obeys the theoretical calculations described in 3.3, with each value going high at the expected threshold temperature. However, for some reason when put in conjunction with all the other subsystems present in the PiHat, the circuit did not output the desired voltages at the temperature thresholds. After multiple conversations with our tutor, it was agreed that for the purpose of the simulation, the resistor values for the voltage dividers were tinkered slightly so that we reached the desired output. All LED’s now turn on at the correct temperatures to meet the system specifications.

Question 4
During the initial stages of the design process, each subsystem of the PiHat was designed using theoretically calculated values that would at a later stage be used when designing the simulated version of the full circuit (all subsystems combined). However, complications were encountered when simulating/testing the Spice model based off the theoretical values not only calculated but the theoretical values taken straight from the datasheet of the TMP335 temperature sensor. When modelling the temperature sensor subsystem (2nd subsystem), it was observed that the temperature coefficient provided by the TMP335 datasheet did not match the simulated results. A new temperature coefficient was then determined for temperature and voltage based on the LT Spice components. This coefficient was applied to the calculations required in working out the resistor values for the op-amp comparator circuits. When individually looking at each subsystem, the desired output was observed. However, this discovery resulted in the simulated voltage divider values calculated for the comparator-LED configurations not giving the desired LED output for the set temperature thresholds when all subsystems were combined. As a result of this subsystem conundrum and changing temperature coefficient complication, when combining all subsystems, the threshold temperatures had to be changed to 0℃, 25℃ and 50℃ and the resistor voltage divider values of each comparator configuration had to be edited until the desired output was achieved. The design process of this PiHat gave the group a great deal of insight into the components that make up this circuit, as well as how LT Spice operates. However, there were various aspects of this assignment that resulted in unanswered questions that had to be solved using fiddling with results and component values rather than known calculations - although this was a direct result of the imported temperature sensor not fitting its datasheet. This assignment has been useful in conveying some of the complexities in design processes.

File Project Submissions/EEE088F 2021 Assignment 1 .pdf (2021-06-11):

## EEE088F 2021

Taine de Buys- DBYTAI001
Michael Altshular -ALTMIC003 David da Costa - DCSDAV001

# Q1 microHAT Concept [5]

Our PiHat is a temperature sensor. The circuit is powered from the 5V output pin (pin 2) from the Raspberry pi and is grounded into pin 6. The purpose of the Hat is to allow the user to get a visual representation of the surrounding temperature. The daughter board takes the 5V input and passes it through a power switch regulator, lowering the voltage to 4.3 volts and allowing for the user to turn the Hat on and off while still being plugged in. If the circuit is closed, an LED will turn on to show that there is a voltage being outputted from the switch. This output will then run into an analogue temperature sensor that will be covered in a waterproof casing, so that it may be used as a probe. 3 LEDs display the output. 1 LED will turn on if the temperature is above 0 degrees Celsius. 2 lights will come on for a temperature of above 15 degrees Celsius, and all 3 lights will turn on for if the temperature is above 30 degrees Celsius. The temperature sensor can be used to measure ambient room temperature, or as a probe to measure the temperature of liquids or inside temperature regulated appliances like freezers and fridges.

# Q2 Requirements [10]

## User role/Scenario1

For a user to be able to see what range the ambient room temperature falls into. This would be for any hobbyist or professional who has their raspberry pi running in different environments. It is important to ensure that the raspberry pi operates at lower temperatures in order to avoid potential damage to components. The lights in the output serve to give the user real time information.
- The Temperature sensor can measure a wide range of temperatures
- Multiple LEDs required to show the different temperatures
- LEDs are easily visible
- That each LED has the same temperature difference between them to make them turn on, this will allow for easier reading.

## User role/Scenario2

For a user who would want to know the temperature of liquids or gasses in a controlled environment. This user would likely be in a scientific or engineering environment and would use the temperature sensor as a probe in order to have the piHat and pi at a safe distance from liquids or gasses that could damage the circuit.
Requirements:
- That the sensor is capable of being placed in liquid.
- That the sensor can be placed at an adequate distance from the piHat and raspberry pi itself.
- LEDs must still be visible if temperature probe is in separate room/ chamber

## User role/Scenario3

For a user to test heat regulated appliances, ranging from fridges and freezers to hotplates and ovens. This user can be anything from home users who want to test the accuracy of their appliances to testing done by the manufacturer.
- The sensor can deal with higher heats.
- The sensor can deal with low temperature environments.
- The sensor is not affected by the heat coming off of the raspberry pi itself.

# Q3 Specifications [20]

## Mechanical Specifications

Requirement | Specification(s) | Acceptance Test Criteria
Temperature can be assessed in liquid. | Waterproof insulation added around probe | While the probe is submerged the temperature will still be measured.
System can be switched off through the Switch Mode Power Supply (SMPS). | A physical switch is opened to stop current flow through to the collector of the transistor part of the SMPS. | System does not operate while the switch is open and operates while closed.

## Electrical Specification

Requirement | Specification(s) | Acceptance Test Criteria
Device is capable reading temperatures between 0-45 degrees | Operating Temperature Range of 0 to 45C | All components selected are rated for operation within given range
LED’s output different temperatures | Comparator circuits will assess the temperature readings and turn on the LEDs accordingly | All LED’s turn on at their correct ranges when tested
System can be switched off through the Switch Mode Power Supply (SMPS). | A physical switch is opened to stop current flow through to the collector of the transistor part of the SMPS. | System does not operate while the switch is open and operates while closed.

## Functional Specifications

Requirement | Specification(s) | Acceptance Test Criteria
Device provides LED feedback | LED1 turns on from 0℃ LED2 turns on from 15℃ LED1 turns on from 30 ℃ | All LED’s turn on at their correct ranges when tested
System can be switched off through the Switch Mode Power Supply (SMPS). | A physical switch can be opened to stop current flow to the rest of the system. | System does not operate while the switch is open.
Temperature can be assessed in liquid. | Temperature sensor submerged in water or in a damp environment outputs different voltages according to the measured temperature. | While the probe is submerged the temperature will still be measured.

LEDs must still be visible if temperature probe is in separate room/ chamber

LEDs placed directly onto
PiHAT

Is temperature still
readable despite sensor in another room.

# Q4 Project Subsystems Block Diagram [5]


# Q5 Subsystem Specifications and Interfaces [30]

## Subsystem 1: Switching power regulator

The power supply can be mechanically controlled by a switch on the circuit. The regulator is also used in order to pick a desired voltage for the bus that will run the other subsystems in the circuit. It will be set to output a voltage of 4.3V.

## Subsystem 2: LED to show circuit is receiving power and is on

When The Circuit is receiving power the LED will turn on.The LED will be a kingbright 2.5V LED.

## Subsystem 3:Temperature sensor

The temperature sensor used is the TMP36. It works with voltages ranging between 2.7V-5.5V. The outputs range between 0 and 1.7V. The input voltage will come from the switching power regulator The output voltage is determined by the formula Degree = (V
out

(mV) − 500)/10

## Subsystem 4:Op amp and output LEDs

The temperature will be assessed using op amps in comparator configuration. As the temperature increases more LEDs will be turned on.
LED 1 will turn on for temperatures above 0 degrees Celsius
LED 2 will turn on for temperatures above 15 degrees Celsius
LED 3 will turn on for temperatures above 25 degrees Celsius
The comparator resistances will be calculated by using the equation V

out = V
in

(R
2

÷ (R

1 + R
2

))

# Q6 Subsystem Draft Circuits [30]

## Subsystem 1: Switching power regulator


## Subsystem 2: LED to show circuit is receiving power and is on


## Subsystem 3: Temperature sensor


## Subsystem 4:Op amp and output LEDs

## Below is a diagram of the entire circuit


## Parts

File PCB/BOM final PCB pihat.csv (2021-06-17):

Id | Designator | Package | Quantity | Designation | Supplier and ref
1 | R17 | R_Axial_DIN0204_L3.6mm_D1.6mm_P1.90mm_Vertical | 1 | 19.53k
2 | R5 | R_Axial_DIN0204_L3.6mm_D1.6mm_P5.08mm_Horizontal | 1 | 15k
3 | R4 | R_Axial_DIN0204_L3.6mm_D1.6mm_P5.08mm_Horizontal | 1 | 200k
4 | Buck/Boost1 | DFN-12-1EP_3x4mm_P0.5mm_EP1.7x3.3mm | 1 | LTC3442
5 | C1 | CP_Radial_D4.0mm_P1.50mm | 1 | 0.001u
6 | C2 | CP_Radial_D4.0mm_P1.50mm | 1 | 10u
7 | C3 | CP_Radial_D4.0mm_P1.50mm | 1 | 470p
8 | C4 | CP_Radial_D4.0mm_P1.50mm | 1 | 0.01u
9 | C5 | CP_Radial_D4.0mm_P1.50mm | 1 | 220p
10 | C6 | CP_Radial_D4.0mm_P1.50mm | 1 | 22u
11 | D1 | D_DO-15_P2.54mm_Vertical_AnodeUp | 1 | DIODE
12 | D2,D3 | D_A-405_P2.54mm_Vertical_AnodeUp | 2 | DIODE
13 | H1,H2,H3,H4 | MountingHole_2.7mm | 4 | MountingHole
14 | J1 | PinHeader_2x20_P2.00mm_Vertical | 1 | Conn_02x20_Odd_Even
15 | L1 | L_Axial_L5.3mm_D2.2mm_P2.54mm_Vertical_Vishay_IM-1 | 1 | 4.7u
16 | LED1,LED2,LED3 | LED_D1.8mm_W1.8mm_H2.4mm_Horizontal_O1.27mm_Z1.6mm | 3 | LED
17 | OP1,OP2,OP3 | TO-5-8 | 3 | OP07
18 | R1 | R_Axial_DIN0204_L3.6mm_D1.6mm_P1.90mm_Vertical | 1 | 1M
19 | R2 | R_Axial_DIN0204_L3.6mm_D1.6mm_P1.90mm_Vertical | 1 | 71.5k
20 | R3,R8,R10,R16 | R_Axial_DIN0204_L3.6mm_D1.6mm_P1.90mm_Vertical | 4 | 1k
21 | R6 | R_Axial_DIN0204_L3.6mm_D1.6mm_P5.08mm_Horizontal | 1 | 340k
22 | R7 | R_Axial_DIN0204_L3.6mm_D1.6mm_P5.08mm_Horizontal | 1 | 135k
23 | R9 | R_Axial_DIN0204_L3.6mm_D1.6mm_P1.90mm_Vertical | 1 | 2.2k
24 | R11 | R_Axial_DIN0204_L3.6mm_D1.6mm_P1.90mm_Vertical | 1 | 24.2k
25 | R12,R15 | R_Axial_DIN0204_L3.6mm_D1.6mm_P5.08mm_Horizontal | 2 | 10k
26 | R13 | R_Axial_DIN0204_L3.6mm_D1.6mm_P5.08mm_Horizontal | 1 | 1k
27 | R14 | R_Axial_DIN0204_L3.6mm_D1.6mm_P5.08mm_Horizontal | 1 | 21.71k
28 | R18 | R_Axial_DIN0204_L3.6mm_D1.6mm_P1.90mm_Vertical | 1 | 10k
29 | TMP1 | SHT1x | 1 | LM135

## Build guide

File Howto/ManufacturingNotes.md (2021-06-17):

**Manufacturing Notes for LM135 PiHat**

A step by step process of manufacturing your own LM135 tempreture sensor PiHat

1. Carefully select your PCB manufacturer
Research for nearby manufacturers, and find one which you believe is reliable
enough to manufacture your PCB.
You should then get quotes on the manufacturing price of the PCB and find which best suit your budget.

2. In order to recieve quotes or begin the manufacturing process you will need to submit the following files:
	* Gerber Files which can be found using the link below
	https://github.com/TainedeBlaze/3088-PiHat-project/tree/main/Gerber%20Files%20Final
	
	* Centroid files which can be found using the following link:
	https://github.com/TainedeBlaze/3088-PiHat-project/tree/main/Pick%20and%20Place%20files
	
	* Bill of materials whcih can be found using the following link:
	https://github.com/TainedeBlaze/3088-PiHat-project/tree/main/PCB's%20Bill%20Of%20Materials

Once you have submitted these files you should be able to manufacture your own PiHat tempreture sensor.

If you wish to manufacture the PCB alone follow the steps in the link below
https://www.pcbcart.com/article/content/PCB-manufacturing-process.html

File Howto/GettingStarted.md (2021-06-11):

**Getting your PiHat started**

Once you have matched the GPIO pins for the Pihat and the Pi, and the pins are connected your tempreture sensor should start working. 
No further actions are required in order for your sensor to begin monitering the ambient room tempreture.

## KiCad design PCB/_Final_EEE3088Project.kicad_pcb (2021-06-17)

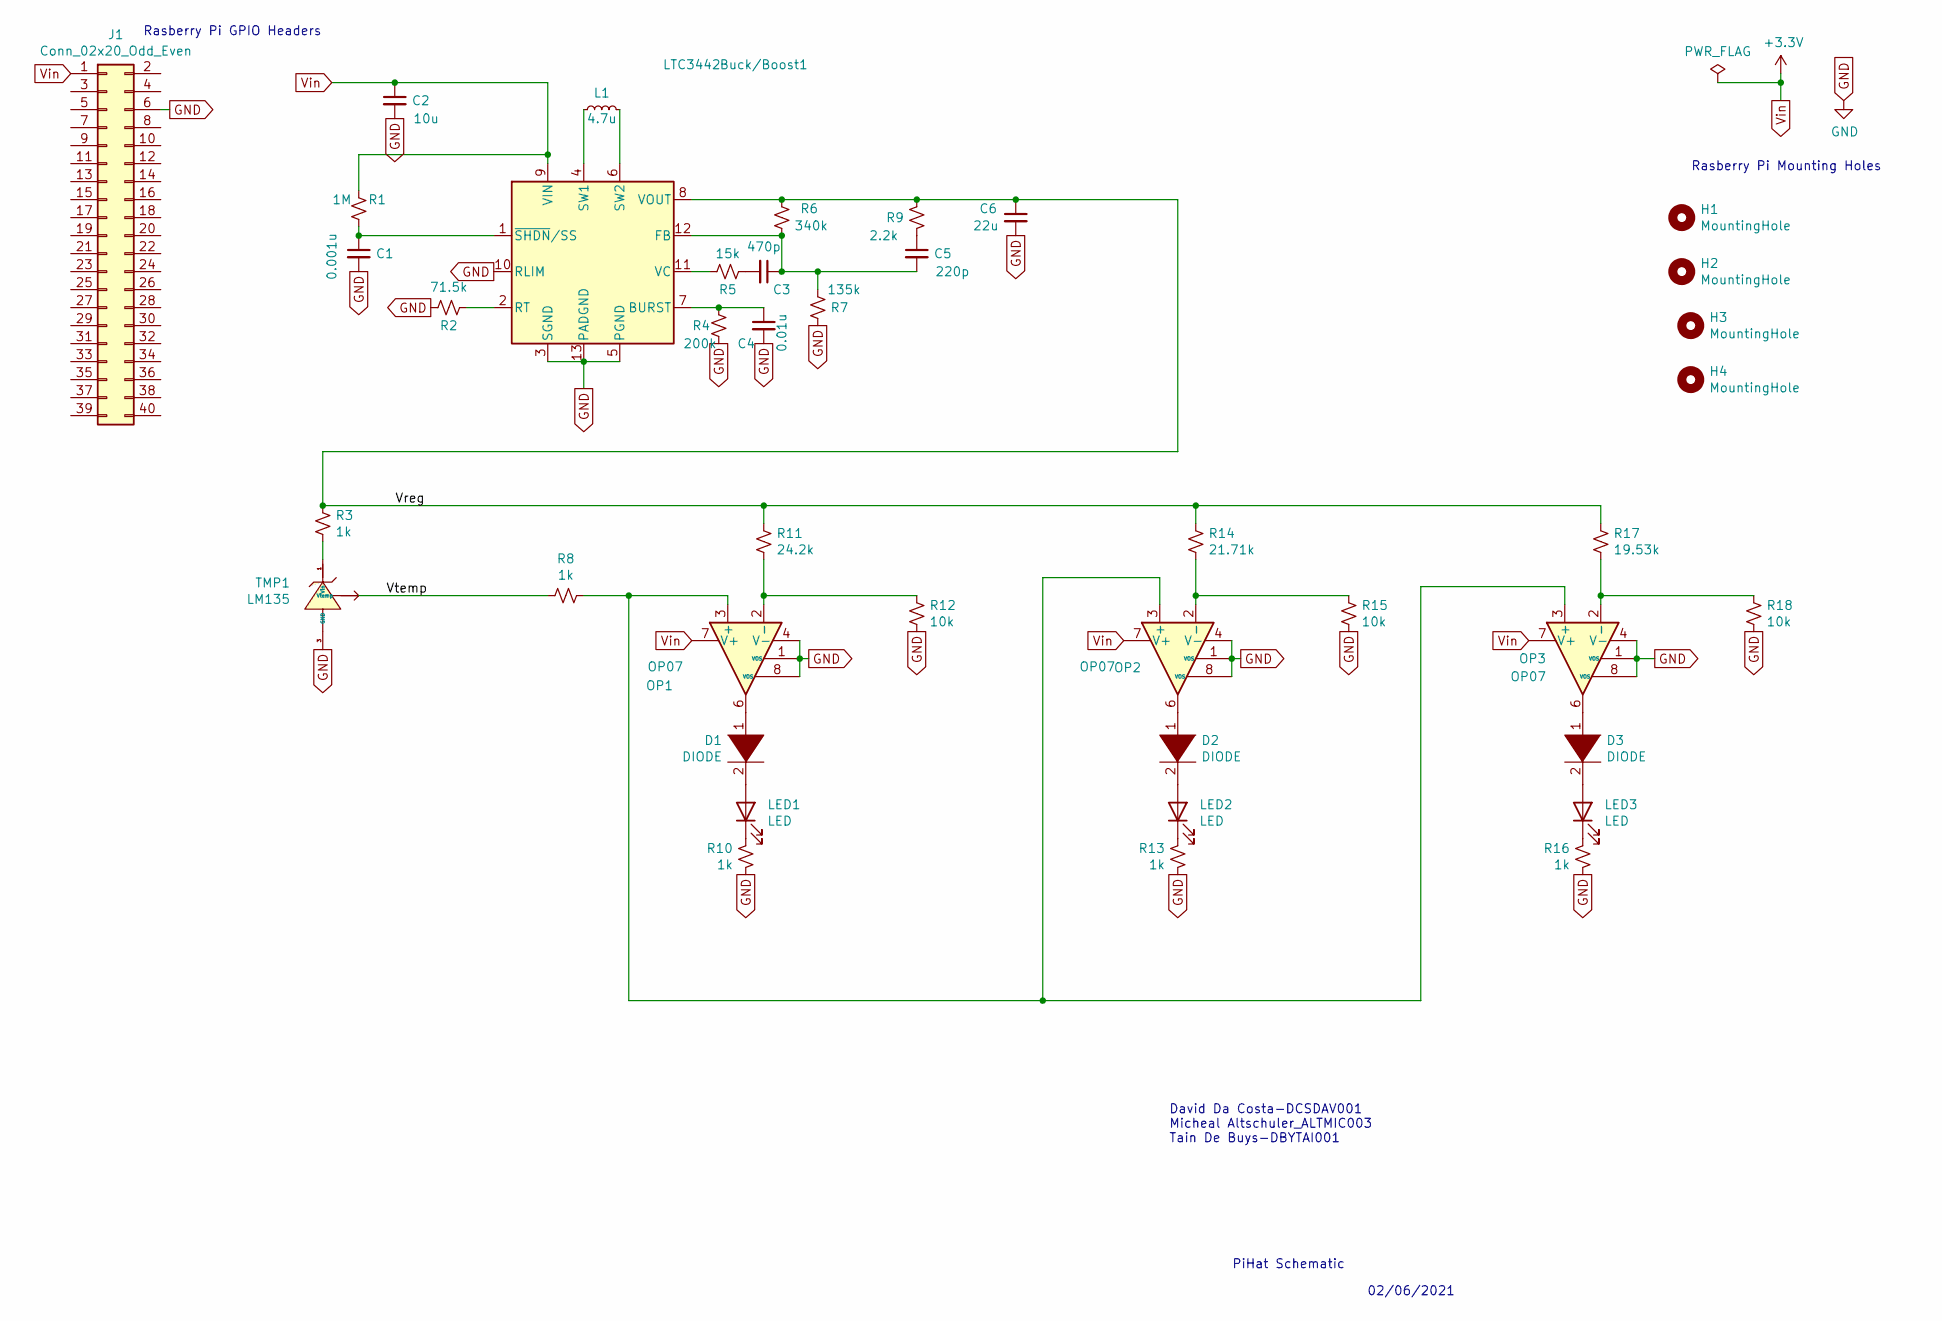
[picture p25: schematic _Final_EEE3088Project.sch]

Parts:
Buck/Boost1: LTC3442; DFN-12-1EP_3x4mm_P0.5mm_EP1.7x3.3mm
C1: 0.001u; CP_Radial_D4.0mm_P1.50mm
C2: 10u; CP_Radial_D4.0mm_P1.50mm
C3: 470p; CP_Radial_D4.0mm_P1.50mm
C4: 0.01u; CP_Radial_D4.0mm_P1.50mm
C5: 220p; CP_Radial_D4.0mm_P1.50mm
C6: 22u; CP_Radial_D4.0mm_P1.50mm
D1: DIODE; D_DO-15_P2.54mm_Vertical_AnodeUp
D2, D3: DIODE; D_A-405_P2.54mm_Vertical_AnodeUp
H1, H2, H3, H4: MountingHole; MountingHole_2.7mm
J1: Conn_02x20_Odd_Even; PinHeader_2x20_P2.00mm_Vertical
L1: 4.7u; L_Axial_L5.3mm_D2.2mm_P2.54mm_Vertical_Vishay_IM-1
LED1, LED2, LED3: LED; LED_D1.8mm_W1.8mm_H2.4mm_Horizontal_O1.27mm_Z1.6mm
OP1, OP2, OP3: OP07; TO-5-8
R1: 1M; R_Axial_DIN0204_L3.6mm_D1.6mm_P1.90mm_Vertical
R2: 71.5k; R_Axial_DIN0204_L3.6mm_D1.6mm_P1.90mm_Vertical
R3, R8, R10, R16: 1k; R_Axial_DIN0204_L3.6mm_D1.6mm_P1.90mm_Vertical
R4: 200k; R_Axial_DIN0204_L3.6mm_D1.6mm_P5.08mm_Horizontal
R5: 15k; R_Axial_DIN0204_L3.6mm_D1.6mm_P5.08mm_Horizontal
R6: 340k; R_Axial_DIN0204_L3.6mm_D1.6mm_P5.08mm_Horizontal
R7: 135k; R_Axial_DIN0204_L3.6mm_D1.6mm_P5.08mm_Horizontal
R9: 2.2k; R_Axial_DIN0204_L3.6mm_D1.6mm_P1.90mm_Vertical
R11: 24.2k; R_Axial_DIN0204_L3.6mm_D1.6mm_P1.90mm_Vertical
R12, R15: 10k; R_Axial_DIN0204_L3.6mm_D1.6mm_P5.08mm_Horizontal
R13: 1k; R_Axial_DIN0204_L3.6mm_D1.6mm_P5.08mm_Horizontal
R14: 21.71k; R_Axial_DIN0204_L3.6mm_D1.6mm_P5.08mm_Horizontal
R17: 19.53k; R_Axial_DIN0204_L3.6mm_D1.6mm_P1.90mm_Vertical
R18: 10k; R_Axial_DIN0204_L3.6mm_D1.6mm_P1.90mm_Vertical
TMP1: LM135; SHT1x

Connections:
/Vreg: Buck/Boost1.8 (VOUT), C6.1, R3.1, R6.1, R9.1, R11.1, R14.1, R17.1
/Vtemp: R8.2, TMP1.~ (Vtemp)
GND: Buck/Boost1.3 (SGND), Buck/Boost1.5 (PGND), Buck/Boost1.10 (RLIM), Buck/Boost1.13 (PADGND), C1.2, C2.2, C4.2, C6.2, J1.6, OP1.1 (VOS), OP1.4 (V-), OP1.8 (VOS), OP2.1 (VOS), OP2.4 (V-), OP2.8 (VOS), OP3.1 (VOS), OP3.4 (V-), OP3.8 (VOS), R2.2, R4.2, R7.2, R10.2, R12.2, R13.2, R15.2, R16.2, R18.2, TMP1.3 (GND)
unnamed: Buck/Boost1.1 (~SHDN~/SS), C1.1, R1.2
unnamed: Buck/Boost1.2 (RT), R2.1
unnamed: Buck/Boost1.4 (SW1), L1.1
unnamed: Buck/Boost1.6 (SW2), L1.2
unnamed: Buck/Boost1.7 (BURST), C4.1, R4.1
unnamed: Buck/Boost1.11 (VC), R5.2
unnamed: Buck/Boost1.12 (FB), C3.1, C5.2, R6.2, R7.1
unnamed: C3.2, R5.1
unnamed: C5.1, R9.2
unnamed: D1.1 (K), OP1.6
unnamed: D1.2 (A), LED1.2 (A)
unnamed: D2.1 (K), OP2.6
unnamed: D2.2 (A), LED2.2 (A)
unnamed: D3.1 (K), OP3.6
unnamed: D3.2 (A), LED3.2 (A)
unnamed: LED1.1 (K), R10.1
unnamed: LED2.1 (K), R13.1
unnamed: LED3.1 (K), R16.1
unnamed: OP1.2 (-), R11.2, R12.1
unnamed: OP1.3 (+), OP2.3 (+), OP3.3 (+), R8.1
unnamed: OP2.2 (-), R14.2, R15.1
unnamed: OP3.2 (-), R17.2, R18.1
unnamed: R3.2, TMP1.1 (Vin)
Vin: Buck/Boost1.9 (VIN), C2.1, J1.1, OP1.7 (V+), OP2.7 (V+), OP3.7 (V+), R1.1

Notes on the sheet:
David Da Costa-DCSDAV001 Micheal Altschuler_ALTMIC003 Tain De Buys-DBYTAI001
PiHat Schematic
02/06/2021
Rasberry Pi Mounting Holes
Rasberry Pi GPIO Headers

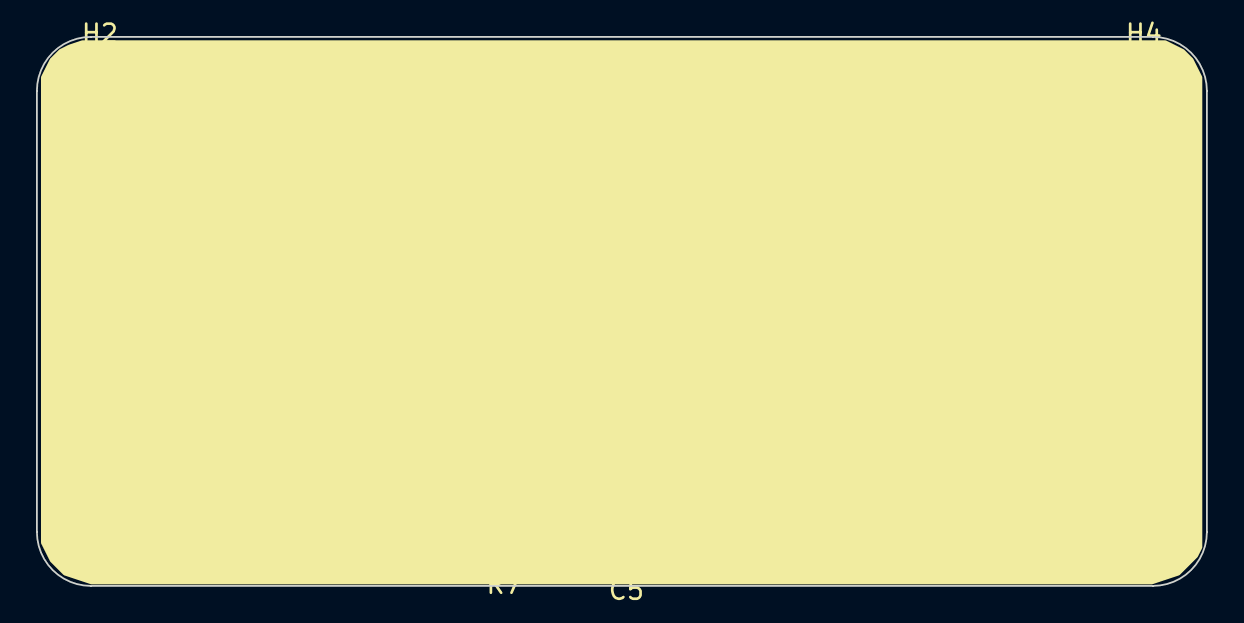
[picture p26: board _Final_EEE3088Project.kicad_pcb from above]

Board: 2 copper layers, 65.0 x 30.5 mm, 41 parts (0 on the bottom side), 26 nets.

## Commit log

2021-06-03 Added Files via Upload
    Added the complete PiHat KiCad Circuit W/O Submodules
    Use these uploads to make PCB
    [EEE3088 PCB Kicad.kicad_pcb, LM135.sch, _Real_EEE3088Project.sch]
2021-06-04 Files for the PCB design and GBR
    [_Real_EEE3088Project-B_Cu.gbr, _Real_EEE3088Project-B_Mask.gbr, _Real_EEE3088Project-B_Paste.gbr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]
2021-06-04 Add files via upload
    All subsystem files.
    [ComparatorLEDSubSystem.kicad_pcb, ComparatorLEDSubSystem.sch, PowerSubSystem.kicad_pcb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]
2021-06-04 Create README.md
    Brief description of Comparator-LED subsystem
2021-06-04 Create README.md
    Brief description of LM135 temperature sensor subsystem
2021-06-04 Create README.md
    Brief description of buck-boost regulator subsystem.
2021-06-11 Add files via upload
    Correct PCB file uploaded
    [_Real_EEE3088Project.kicad_pcb]
2021-06-11 Delete EEE3088 PCB Kicad.kicad_pcb
    Deleted dummy PCB
    [EEE3088 PCB Kicad.kicad_pcb]
2021-06-11 Add files via upload
    KiCad Schematic re-uploaded into a single file
    [LM135.sch, _Real_EEE3088Project.sch]
2021-06-11 Add files via upload
    Added bill of materials
    [BOM for PCB .csv]
2021-06-11 Add files via upload
    KiCad schematic screenshot of LTC3442.
2021-06-11 Add files via upload
    Simulations of Comparator-LED subsystem for T = 2 degrees, T = 26 degrees, T = 52 degrees [Celcius].
2021-06-11 Add files via upload
    KiCad schematic of the Comparator-LED subsystem.
2021-06-11 Add files via upload
    Added how to on manufacturing your own PCB
2021-06-11 Add files via upload
    KiCad schematic for the LM135 temperature sensor submodule.
2021-06-11 Add files via upload
    Screenshots of both the 2D and 3D PCB's.
2021-06-17 Final PiHat KiCad
    [_Final_EEE3088Project-B_Cu.gbr, _Final_EEE3088Project-B_Mask.gbr, _Final_EEE3088Project-B_Paste.gbr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]
2021-06-17 Delete PCB and Gerber Files directory
    Deleted V1
    [_Real_EEE3088Project-B_Cu.gbr, _Real_EEE3088Project-B_Mask.gbr, _Real_EEE3088Project-B_Paste.gbr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]
